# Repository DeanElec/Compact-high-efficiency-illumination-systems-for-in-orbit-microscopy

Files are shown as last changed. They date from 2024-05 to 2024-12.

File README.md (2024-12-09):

# Compact-high-efficiency-illumination-systems-for-in-orbit-microscopy
Presents all data associated with the development of my thesis for a 3rd year final year project at the University of Nottingham
***
## Project Overview
The aim of the project was to develop a solution to image specimens such as C. elegans and similar sized organisms in bright field and darkfield modalities, that would fit in a 1U Cube Sat (10cm^3) for less than £200.

***
## Project Evaluation
The project overall was a success as the system was able to take both bright field and dark field images with high enough resolution and resolving power to accurate image Diatoms, C.elegans and Buccal Epithelial Cells, however the code was not developed to run autonomously but the code developed for the Raspberry Pi as part of the GUI control could be quickly and easily modified to make a autonomous system due directly relevent code wrote in a generic way such that it can be reused.

Due to cost restraint a set of cheap lenses were used, but the datasheet that came with these lenses had all incorrect parameters such as FOV or MOD. For this reason significant time was spent characterising the lenses so the data could be relied upon.

For full evaluation of the design and the data my thesis can be found in the thesis directory.

### Images Taken on the Microscope
***
#### Diatoms Bright and Dark Field
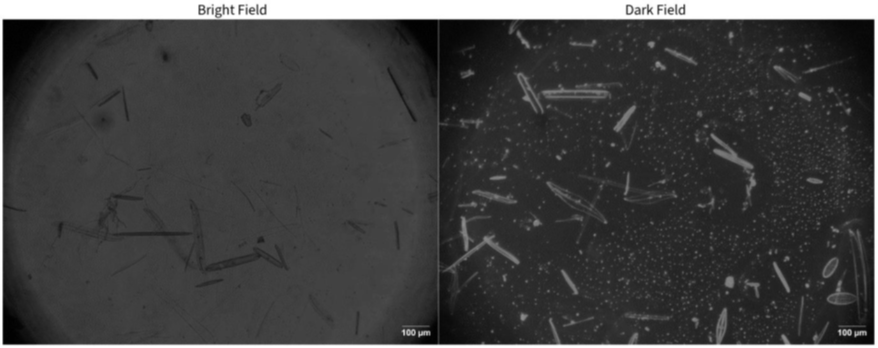
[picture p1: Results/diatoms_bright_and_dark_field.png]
Diatoms Bright and Dark Field


#### Buccal Epithelial Cells Bright and Dark Field
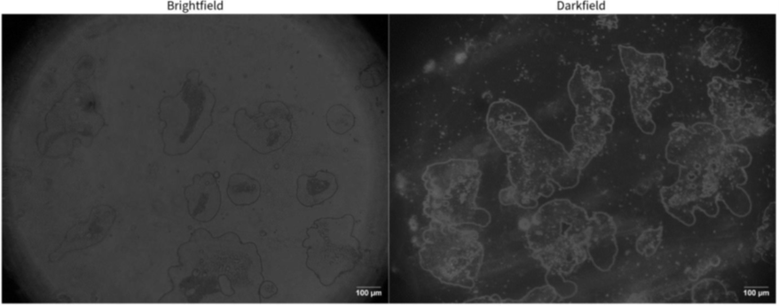
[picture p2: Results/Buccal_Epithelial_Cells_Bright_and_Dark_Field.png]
Buccal Epithelial Bright and Dark Field

***

### CAD Images of the Microscope System
***
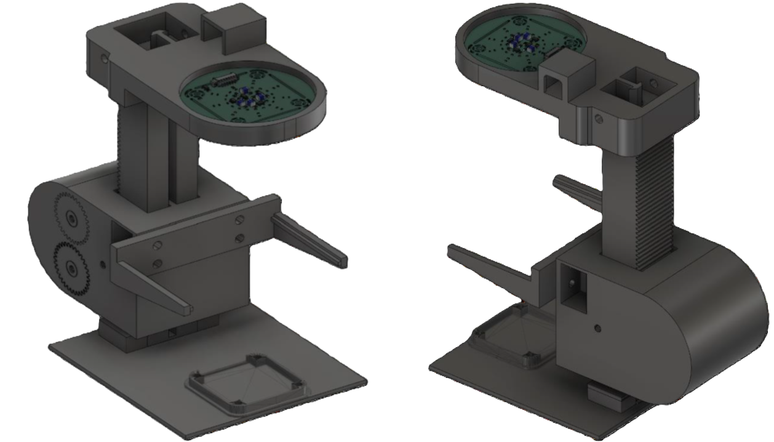
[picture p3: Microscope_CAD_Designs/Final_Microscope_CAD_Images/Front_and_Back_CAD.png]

***

## Control Interface
For ease of testing / taking images with the microscope a GUI was developed in C++ using QT to control all aspects of the microscope remotely when connected on the same network. This allowed for control of:
- Automatic transfer of the images taken on the Raspberry Pi to the host PC
- Save directory locations for both the Raspberry Pi side and the host PC side for saving the recieved images from the Raspberry Pi
- Brightness and PWM frequency controll of all 3 colour rings plus the central cyan LED used for rhinefield illumination
- Multiple basic (binary) image processing options such as the type of demosaic algorithm, and others
- Advanced image processing options such as custom brightness, white balance and gamma options
- Finally a button to allow the user to take an image once parameters have been set by the user
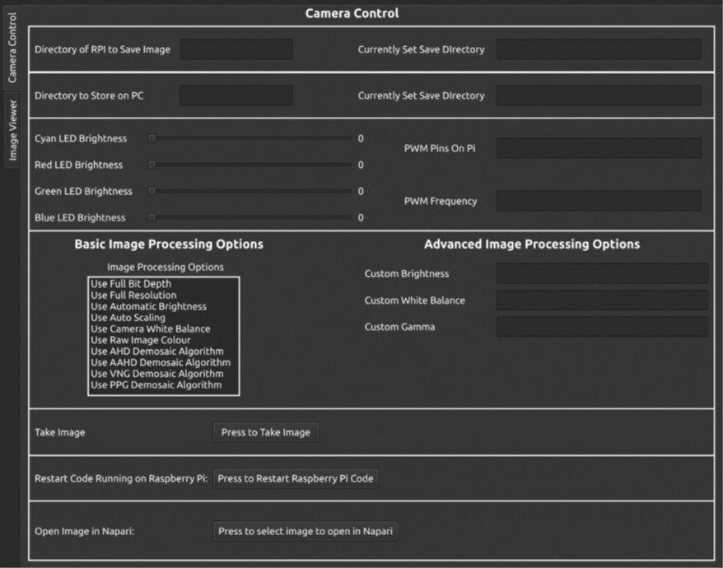
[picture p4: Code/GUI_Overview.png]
GUI Overview


## Future Work / Improvements
If this project was to be taken forward, the current PCB's would work but really require a PCB assembly house to manufacture and populate the board as it is too densely packed with too small component to do by hand and was a main struggle in the project.

That said an improved design for the illumination board has already been created and tested based on addressable SK6805 LEDs and will be uploaded to this github repo in the future once the driver board for it has been finalised and tested.
The new design will be able to be controlled via a plug-in for the open source microscopy software micro-manager, it will provide a GUI that will allow the user to control the illumination system from the host PC running micro-manager, as micro-manager
was wrote in java it is inherently cross platform and thus the plug-in should work for any OS.

Also as potential future upgrades would be to add a form of auto focus as although the microscope worked and gathered detailed images it was hard to get the specimens in focus.
***

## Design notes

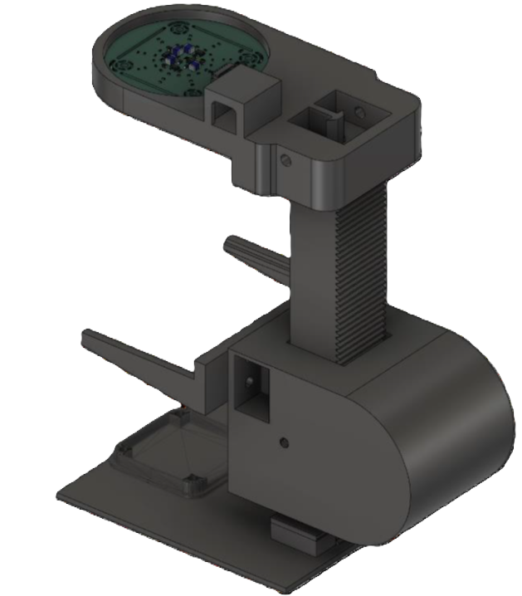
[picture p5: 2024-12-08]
Microscope_CAD_Designs/Final_Microscope_CAD_Images/Final_microscope_design_back.png

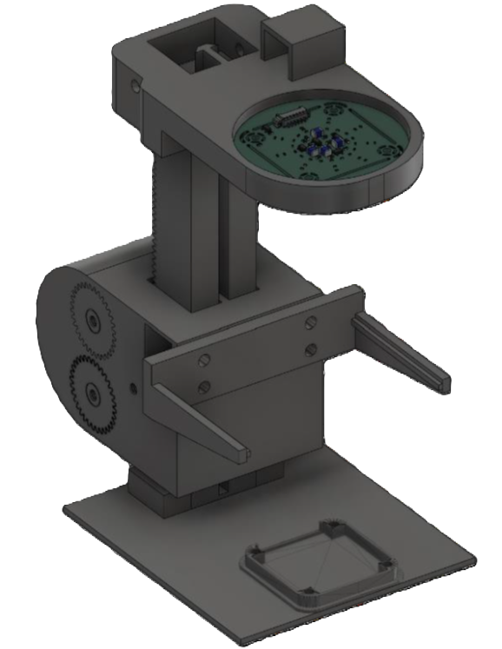
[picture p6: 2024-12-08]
Microscope_CAD_Designs/Final_Microscope_CAD_Images/Final_microscope_front.png

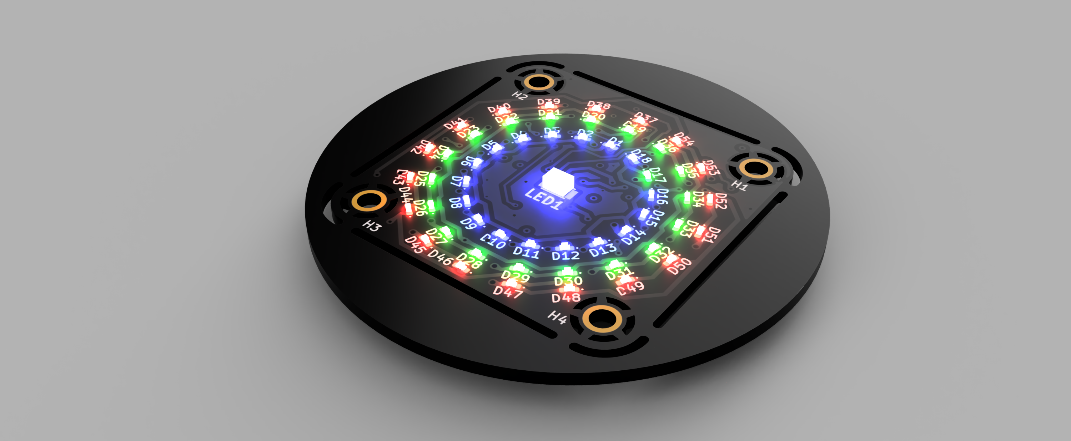
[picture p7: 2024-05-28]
PCB_Design/PCB_3_LED_Rings_Multiple_Thor_Labs_Mounting_Compatibility/LED_Revised_New_Rendered.png

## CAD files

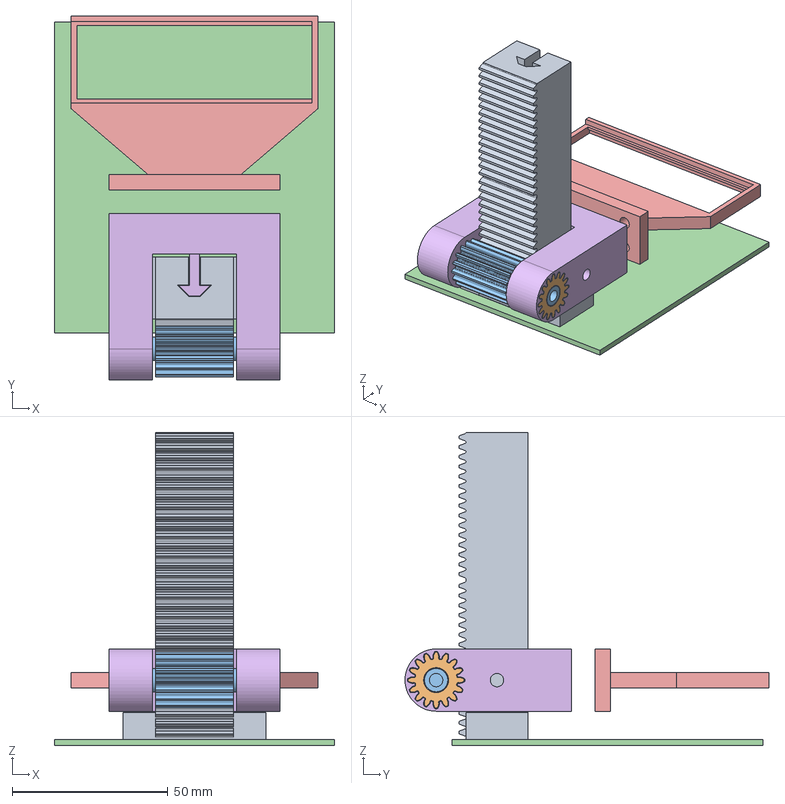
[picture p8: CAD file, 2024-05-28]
Microscope_CAD_Designs/Microscope_Stand_V1/Microscope_CAD_Design_V1_Files/Step_Files/Stand v1 assembled.step
90.0 x 116.9 x 100.5 mm
Rack Gear (16 teeth)
Spur Gear (16 teeth)
Spur to Rack Connector (2)
Spur to Rack Connector Left
Specimen Holder Universal Connector
Camera Holder
Base Plate Dimensions
Specimen_slide_holder

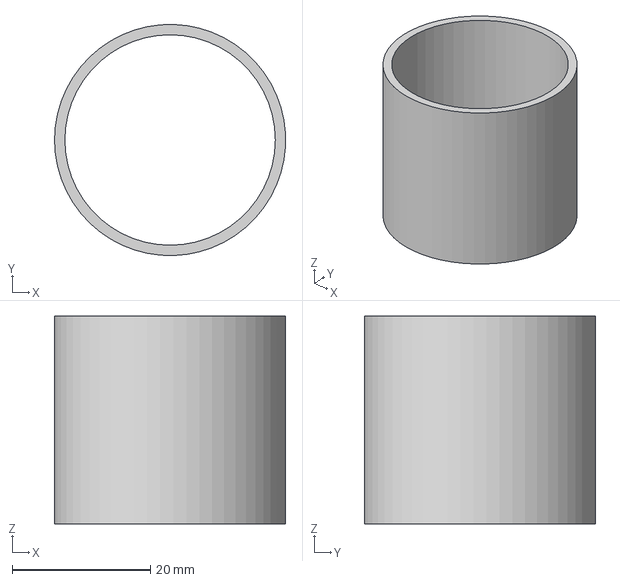
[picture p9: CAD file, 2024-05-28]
Microscope_CAD_Designs/Lens_Couplers_and_Adapters/Step_Files/m07-m03 lens coupler v2.step
33.4 x 33.4 x 30.0 mm

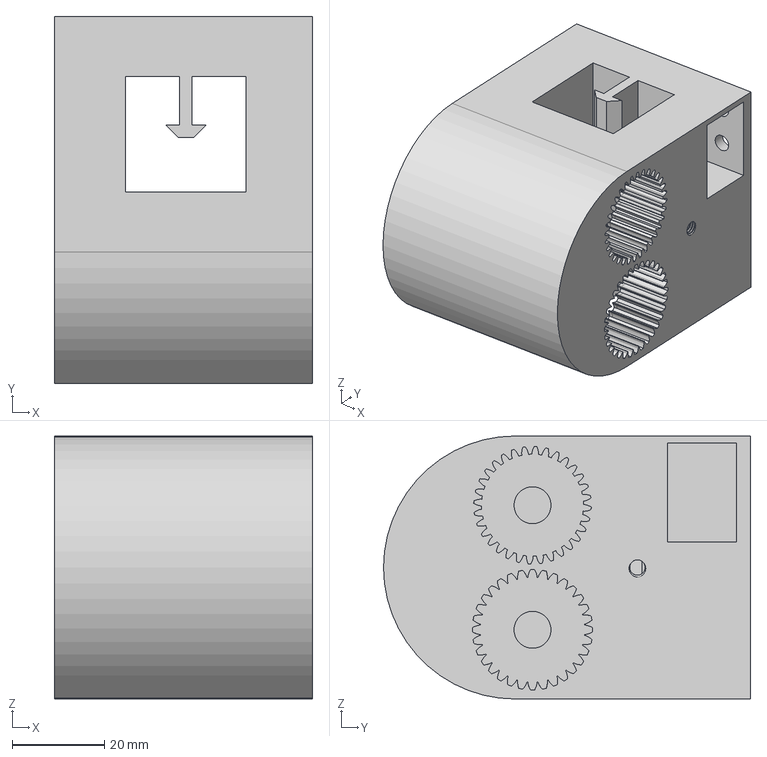
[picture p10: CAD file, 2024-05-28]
Microscope_CAD_Designs/Microscope_CAD_Design_V2_Files/Step_Files/New Spur to Rack Connector v22.step
56.0 x 79.6 x 57.0 mm

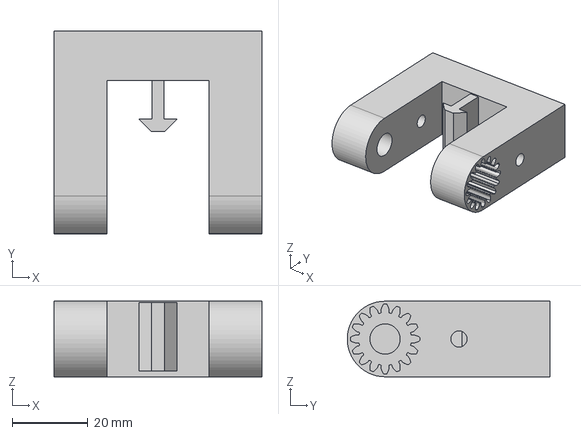
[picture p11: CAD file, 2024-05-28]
Microscope_CAD_Designs/Microscope_Stand_V1/Microscope_CAD_Design_V1_Files/Step_Files/Spur to rack connector v3.step
55.0 x 53.6 x 20.0 mm

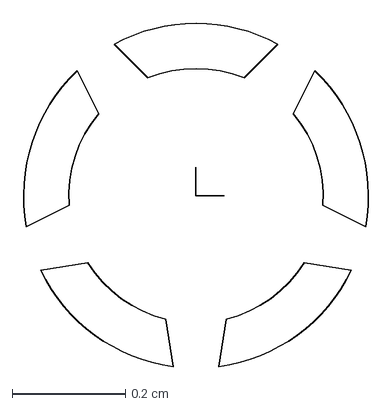
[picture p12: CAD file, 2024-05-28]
PCB_Design/PCB_3_LED_Rings_Multiple_Thor_Labs_Mounting_Compatibility/Hole Edge Cuts 2.5mm v6.dxf
0.637 x 0.62 cm

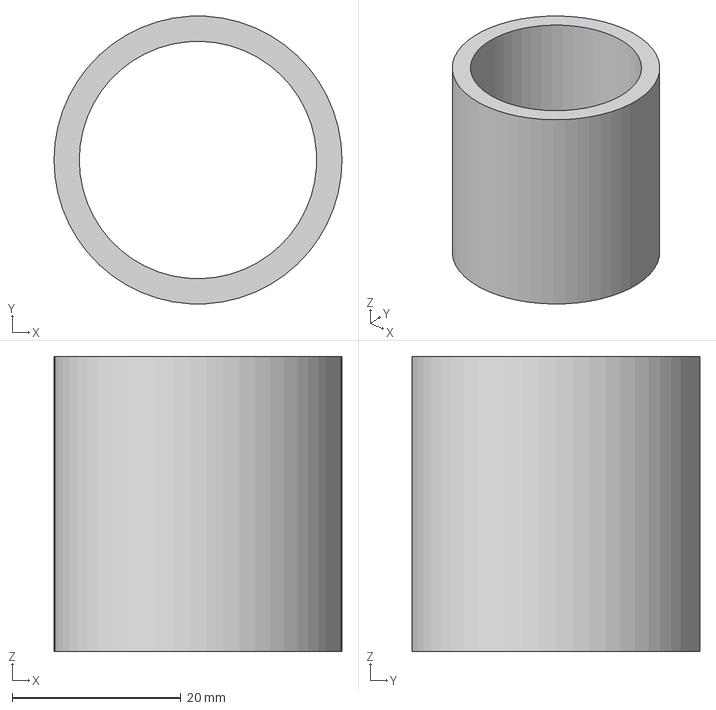
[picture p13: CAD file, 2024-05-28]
Microscope_CAD_Designs/Lens_Couplers_and_Adapters/Step_Files/Lens_to_Lens_Connector v3.step
34.1 x 34.1 x 35.0 mm

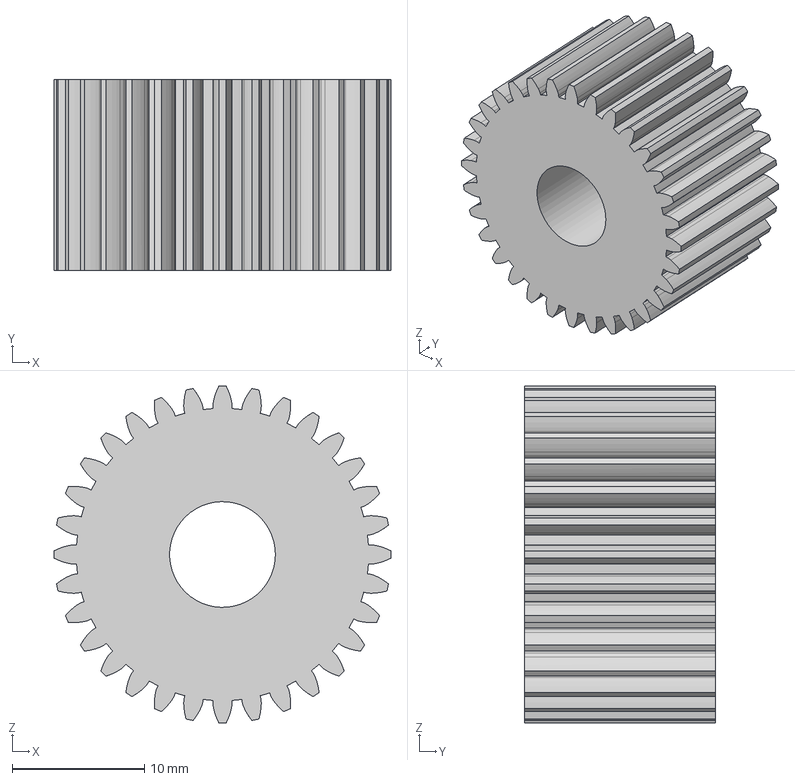
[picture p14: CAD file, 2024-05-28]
Microscope_CAD_Designs/Microscope_CAD_Design_V2_Files/Step_Files/New Spur Gear Shim.step
25.5 x 14.4 x 25.5 mm

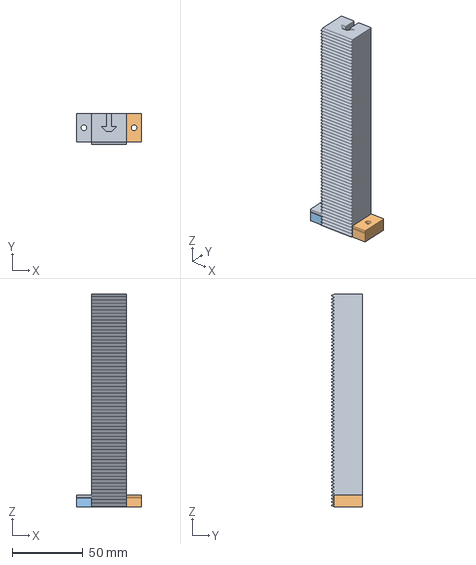
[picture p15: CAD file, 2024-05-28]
Microscope_CAD_Designs/Microscope_CAD_Design_V2_Files/Step_Files/Rack_Gear_New_Version v6.step
46.0 x 21.7 x 150.8 mm

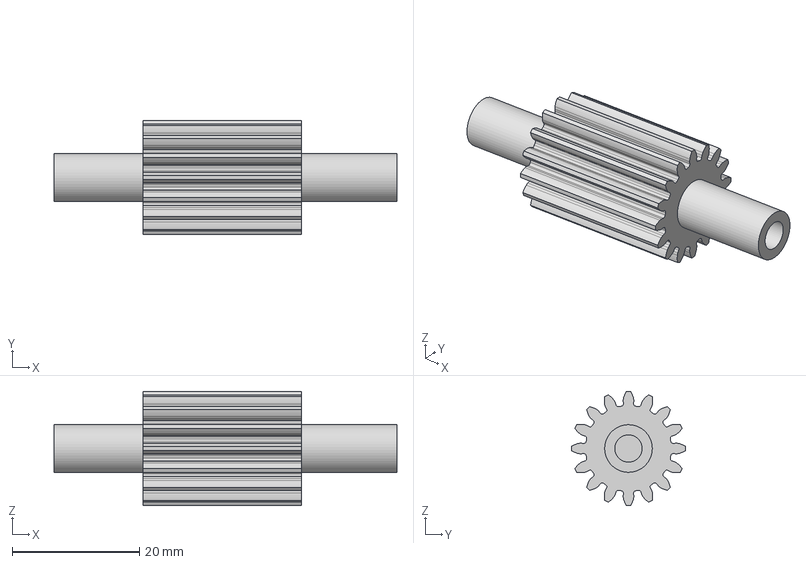
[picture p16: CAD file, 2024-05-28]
Microscope_CAD_Designs/Microscope_Stand_V1/Microscope_CAD_Design_V1_Files/Step_Files/Spur and Rod v3.step
54.0 x 18.0 x 18.0 mm

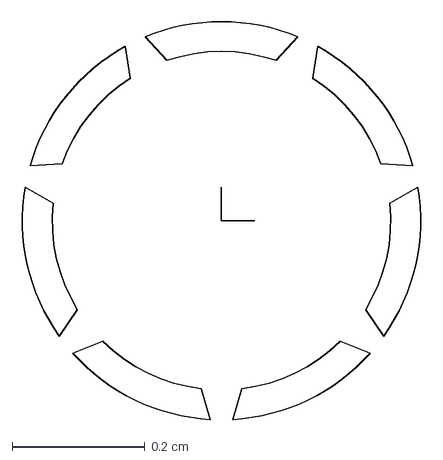
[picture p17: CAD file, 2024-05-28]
PCB_Design/PCB_3_LED_Rings_Multiple_Thor_Labs_Mounting_Compatibility/Hole Edge Cuts v5.dxf
0.618 x 0.607 cm

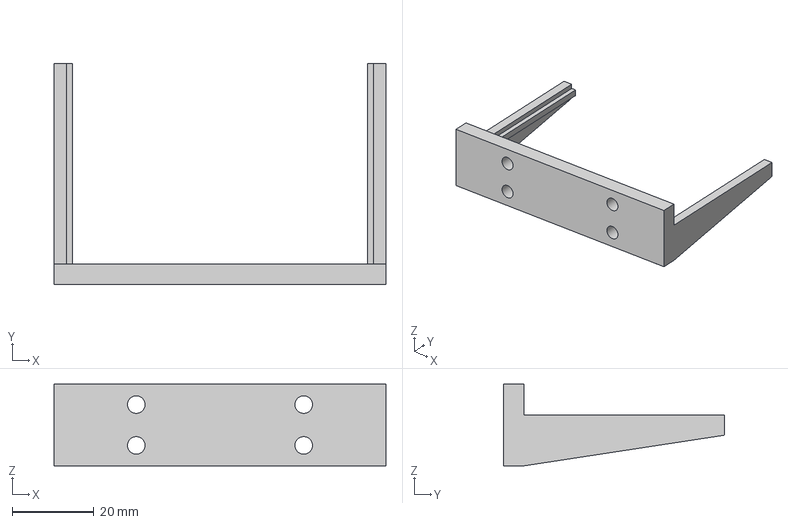
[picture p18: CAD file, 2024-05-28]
Microscope_CAD_Designs/Microscope_CAD_Design_V2_Files/Step_Files/New_Specimen_Holder_Wont_Obstruct_LED_Ring v5.step
81.3 x 54.1 x 20.0 mm

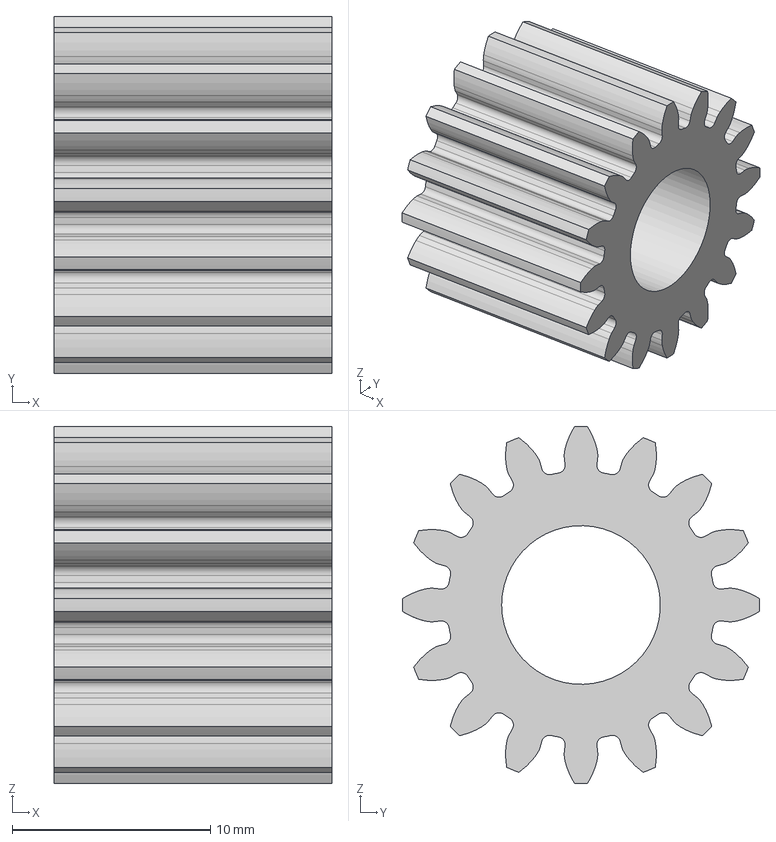
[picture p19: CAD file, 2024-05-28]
Microscope_CAD_Designs/Microscope_Stand_V1/Microscope_CAD_Design_V1_Files/Step_Files/Spur gear shaped shim v2.step
14.0 x 18.0 x 18.0 mm

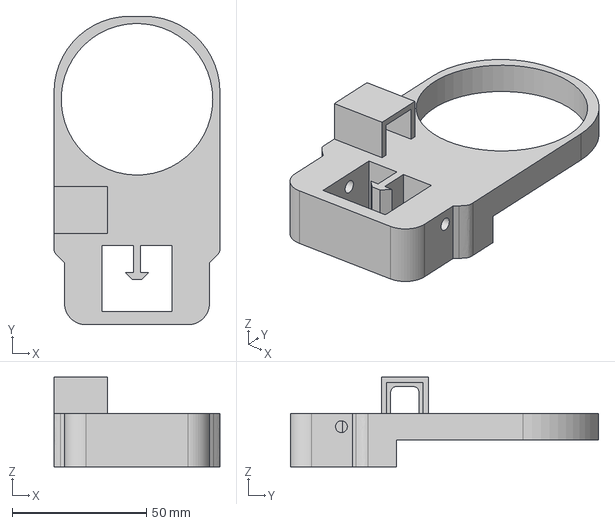
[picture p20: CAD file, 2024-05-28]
Microscope_CAD_Designs/Microscope_CAD_Design_V2_Files/Step_Files/Illumination_PCB_Holder v4.step
61.9 x 115.0 x 33.5 mm

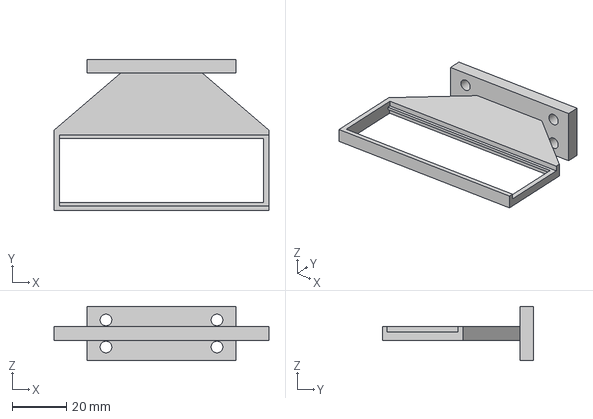
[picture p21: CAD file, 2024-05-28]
Microscope_CAD_Designs/Microscope_Stand_V1/Microscope_CAD_Design_V1_Files/Step_Files/Specimen_slide_holder v2.step
79.4 x 55.9 x 20.0 mm

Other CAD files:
Microscope_CAD_Designs/Lens_Couplers_and_Adapters/Step_Files/Lens_Adapter_m02_m07 v4.step
Microscope_CAD_Designs/Microscope_CAD_Design_V2_Files/Step_Files/New_Spur_and_Rod v4.step
Microscope_CAD_Designs/Microscope_Stand_V1/Microscope_CAD_Design_V1_Files/Step_Files/Camera_Holder v3.step
Microscope_CAD_Designs/Microscope_Stand_V1/Microscope_CAD_Design_V1_Files/Step_Files/Base Plate Dimensions v2.step
Microscope_CAD_Designs/Lens_Couplers_and_Adapters/Fusion_360_Files/Lens_Adapter_m02_m07 v4.f3d
Microscope_CAD_Designs/Lens_Couplers_and_Adapters/Fusion_360_Files/Lens_to_Lens_Connector v3.f3d
Microscope_CAD_Designs/Lens_Couplers_and_Adapters/Fusion_360_Files/m07-m03 lens coupler v2.f3d
Microscope_CAD_Designs/Microscope_CAD_Design_V2_Files/Fusion_360_Files/Illumination_PCB_Holder v3.f3d
Microscope_CAD_Designs/Microscope_CAD_Design_V2_Files/Fusion_360_Files/New_Specimen_Holder v5.f3d
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

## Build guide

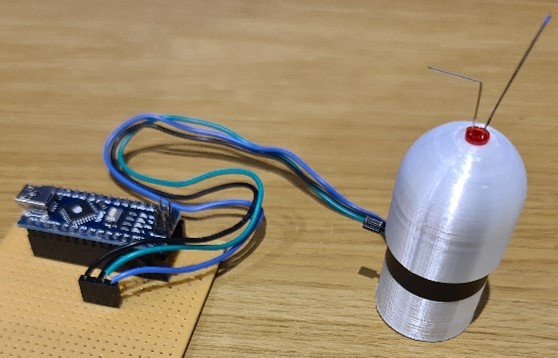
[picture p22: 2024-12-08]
Lens-characterisation/light_transmission_efficiency/light_intensity_setup_with_a_lens.jpg

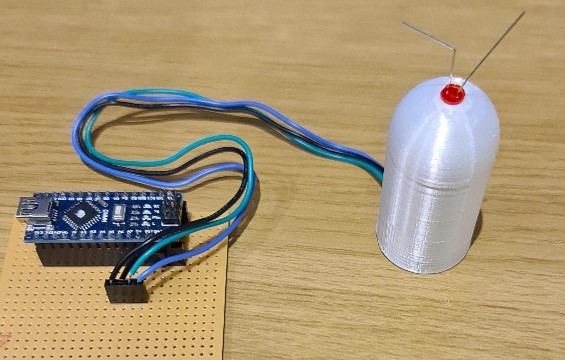
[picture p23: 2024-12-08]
Lens-characterisation/light_transmission_efficiency/no_lens_light_intensity_setup_for_baseline.jpg

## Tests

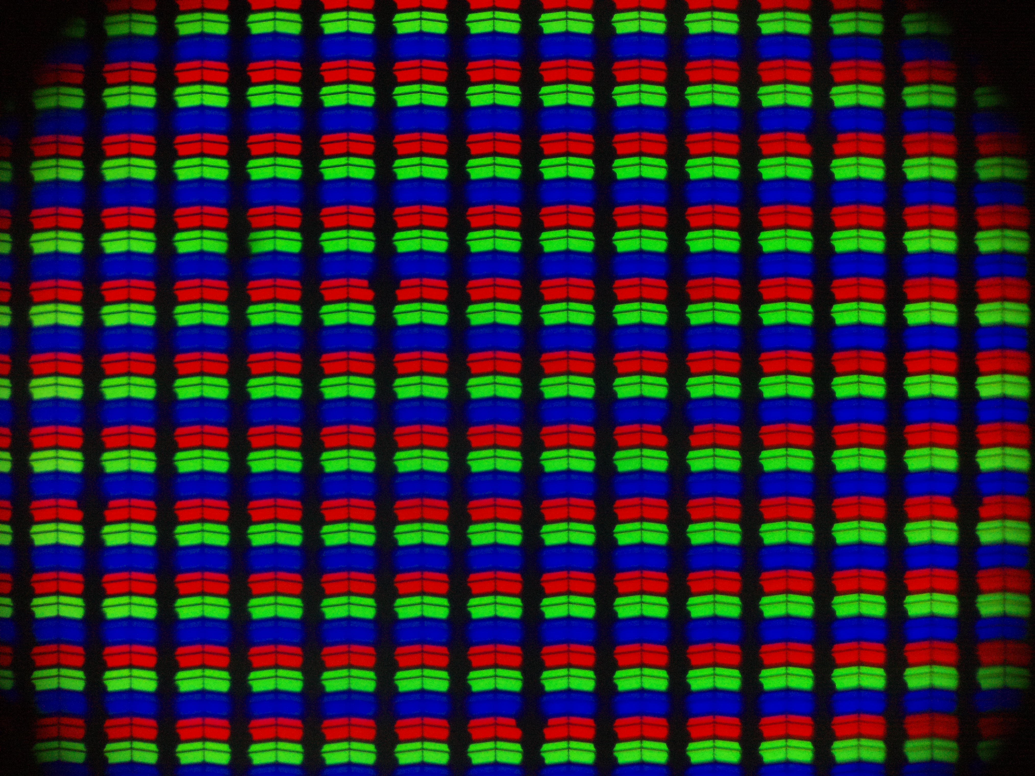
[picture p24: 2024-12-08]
Lens-characterisation/resolving_power_and_chromatic_aberration/rgb_pixels_M02_M01_new.jpeg

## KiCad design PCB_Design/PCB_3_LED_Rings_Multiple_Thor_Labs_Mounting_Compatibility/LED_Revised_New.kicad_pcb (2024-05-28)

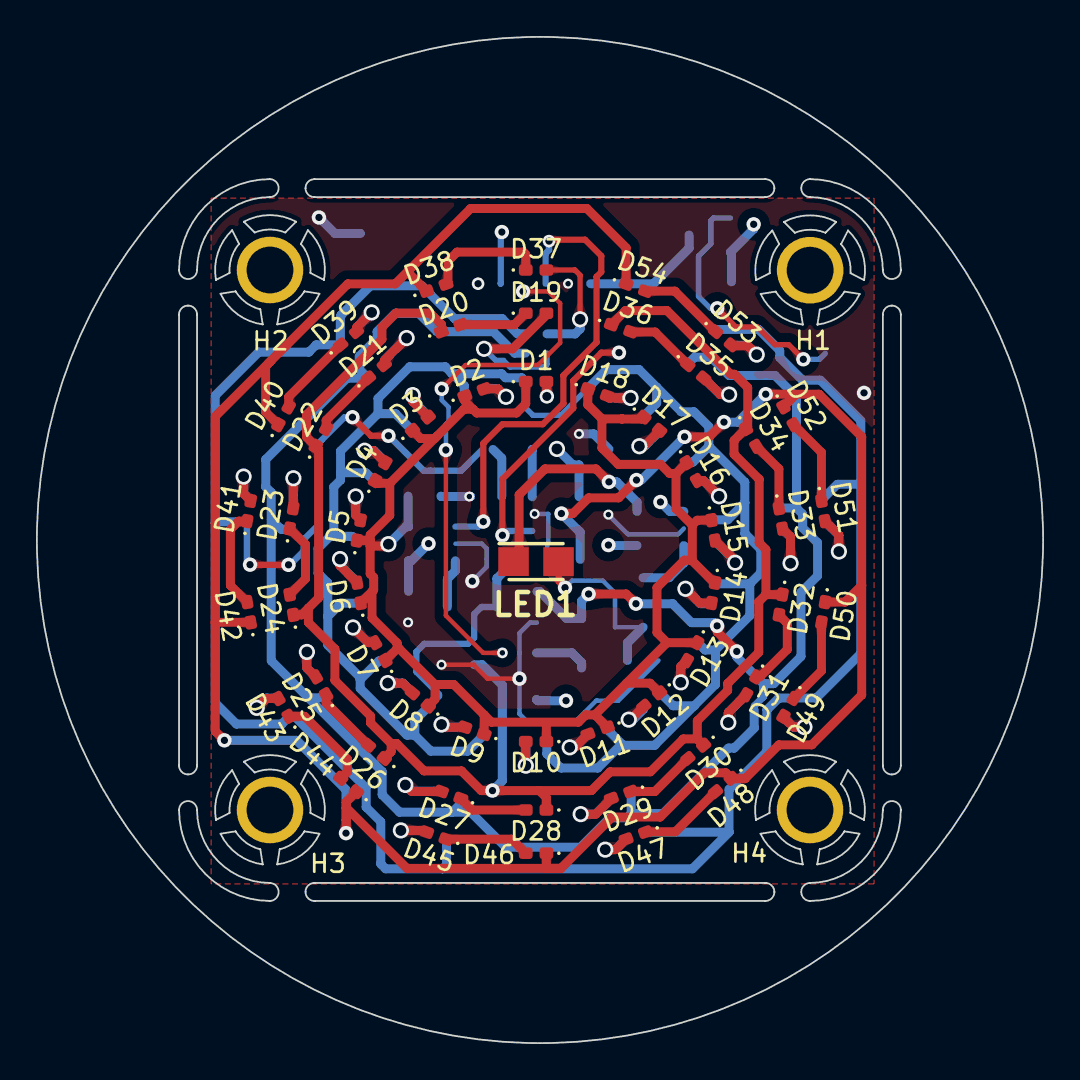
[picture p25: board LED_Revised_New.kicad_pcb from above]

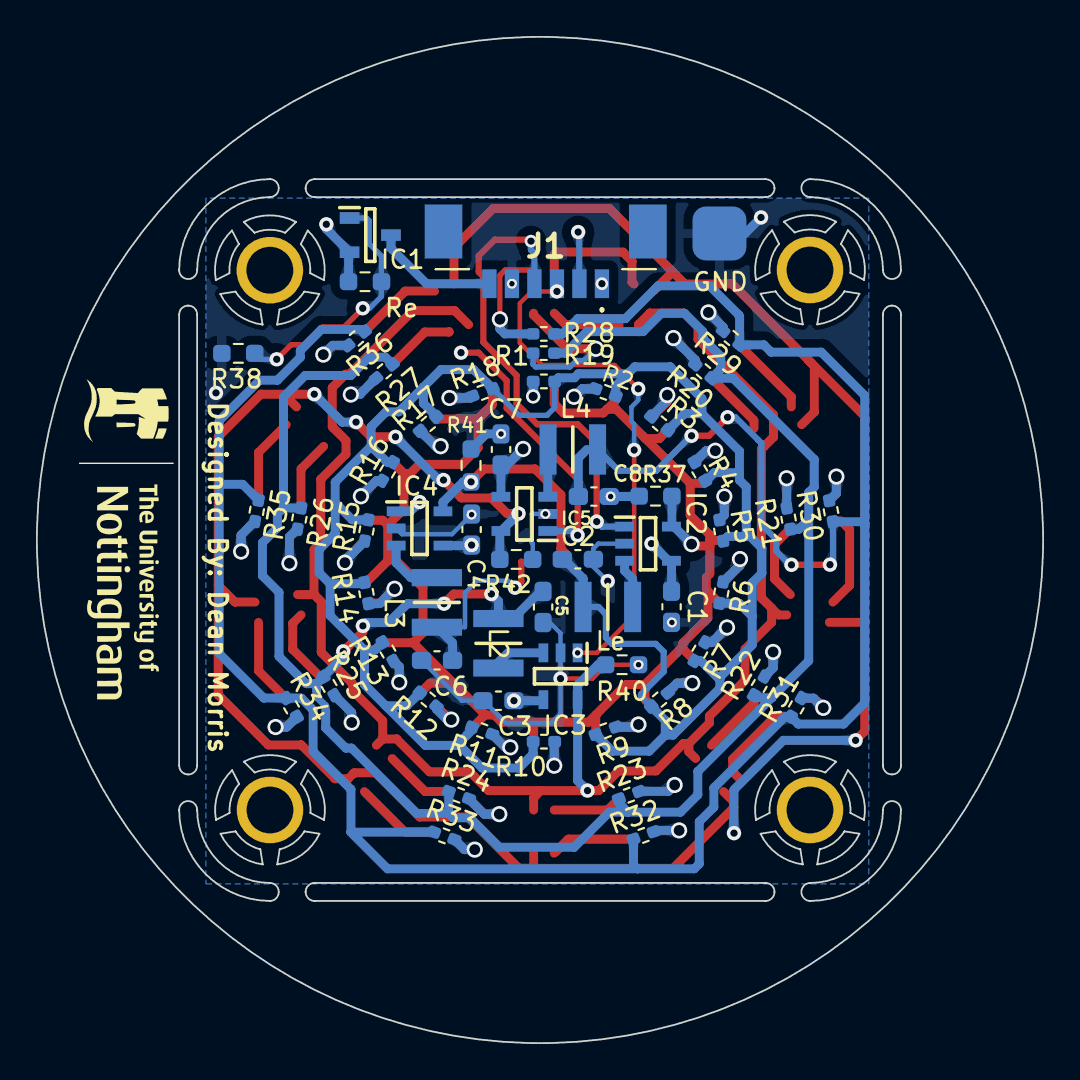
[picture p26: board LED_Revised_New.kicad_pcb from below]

Board: 4 copper layers, 55.9 x 55.9 mm, 120 parts (61 on the bottom side), 74 nets.

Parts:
C1, C2, C3, C4, C5, C6, C7, C8: 10uF; C_0603_1608Metric_Pad1.08x0.95mm_HandSolder
D1, D2, D3, D4, D5, D6, D7, D8, D9, D10, D11, D12, D13, D14, D15, D16, D17, D18, D19, D20, D21, D22, D23, D24, D25, D26, D27, D28, D29, D30, D31, D32, D33, D34, D35, D36, D37, D38, D39, D40, D41, D42, D43, D44, D45, D46, D47, D48, D49, D50, D51, D52, D53, D54: LED_0402_1005Metric_Pad0.77x0.64mm_HandSolder
H1, H2, H3, H4: MountingHole_Pad; M2.5_Mountinh_Hole
H6: SMD_Ground_Pad; 3mm_Ground_Pad
IC1: FDN360P; SOT95P251X112-3N
IC2, IC3, IC4, IC5: PAM2804AAB010; SOT95P280X100-5N
J1: Conn_01x06_Socket; 532610671
L2, L3, L4: 4.7uH; DFE322520FD1R0MP2
LED1: AA3021VRCBS_A; LEDM3020X150N
Le: 4.7uH; DFE322520FD1R0MP2
R1, R2, R3, R4, R5, R6, R7, R8, R9, R10, R11, R12, R13, R14, R15, R16, R17, R18, R19, R20, R21, R22, R23, R24, R25, R26, R27, R28, R29, R30, R31, R32, R33, R34, R35, R36: 100; R_0402_1005Metric_Pad0.72x0.64mm_HandSolder
R37, R40, R42: R; R_0603_1608Metric_Pad0.98x0.95mm_HandSolder
R38: 10k; R_0603_1608Metric_Pad0.98x0.95mm_HandSolder
R41: 3.6; R_0603_1608Metric_Pad0.98x0.95mm_HandSolder
Re: 10k; R_0603_1608Metric_Pad0.98x0.95mm_HandSolder

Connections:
/SW: IC4.3 (SW), L3.2
Blue_LED_End: D1.1 (K), D2.1 (K), D3.1 (K), D4.1 (K), D5.1 (K), D6.1 (K), D7.1 (K), D8.1 (K), D9.1 (K), D10.1 (K), D11.1 (K), D12.1 (K), D13.1 (K), D14.1 (K), D15.1 (K), D16.1 (K), D17.1 (K), D18.1 (K), IC2.5 (FB), R37.1
Blue_LED_Start: C2.1, Le.1, R1.1, R2.1, R3.1, R4.1, R5.1, R6.1, R7.1, R8.1, R9.1, R10.1, R11.1, R12.1, R13.1, R14.1, R15.1, R16.1, R17.1, R18.1
GND: C1.2, C2.2, C3.2, C4.2, C5.2, C6.2, C7.2, C8.2, H6.1, IC2.2 (GND), IC3.2 (GND), IC4.2 (GND), IC5.2 (GND), J1.5, R37.2, R38.1, R40.2, R41.2, R42.2
Green_LED_End: D20.1 (K), D22.1 (K), D24.1 (K), D26.1 (K), D28.1 (K), D30.1 (K), D32.1 (K), D34.1 (K), D36.1 (K), IC3.5 (FB), R40.1
Green_LED_Start: C5.1, L2.1, R19.1, R20.1, R21.1, R22.1, R23.1, R24.1, R25.1, R26.1, R27.1
unnamed: D1.2 (A), R1.2
unnamed: D2.2 (A), R2.2
unnamed: D3.2 (A), R3.2
unnamed: D4.2 (A), R4.2
unnamed: D5.2 (A), R5.2
unnamed: D6.2 (A), R6.2
unnamed: D7.2 (A), R7.2
unnamed: D8.2 (A), R8.2
unnamed: D9.2 (A), R9.2
unnamed: D10.2 (A), R10.2
unnamed: D11.2 (A), R11.2
unnamed: D12.2 (A), R12.2
unnamed: D13.2 (A), R13.2
unnamed: D14.2 (A), R14.2
unnamed: D15.2 (A), R15.2
unnamed: D16.2 (A), R16.2
unnamed: D17.2 (A), R17.2
unnamed: D18.2 (A), R18.2
unnamed: D19.2 (A), R19.2
unnamed: D19.1 (K), D20.2 (A)
unnamed: D21.2 (A), R20.2
unnamed: D21.1 (K), D22.2 (A)
unnamed: D23.2 (A), R21.2
unnamed: D23.1 (K), D24.2 (A)
unnamed: D25.2 (A), R22.2
unnamed: D25.1 (K), D26.2 (A)
unnamed: D27.2 (A), R23.2
unnamed: D27.1 (K), D28.2 (A)
unnamed: D29.2 (A), R24.2
unnamed: D29.1 (K), D30.2 (A)
unnamed: D31.2 (A), R25.2
unnamed: D31.1 (K), D32.2 (A)
unnamed: D33.2 (A), R26.2
unnamed: D33.1 (K), D34.2 (A)
unnamed: D35.2 (A), R27.2
unnamed: D35.1 (K), D36.2 (A)
unnamed: D37.2 (A), R28.2
unnamed: D37.1 (K), D38.2 (A)
unnamed: D39.2 (A), R29.2
unnamed: D39.1 (K), D40.2 (A)
unnamed: D41.2 (A), R30.2
unnamed: D41.1 (K), D42.2 (A)
unnamed: D43.2 (A), R31.2
unnamed: D43.1 (K), D44.2 (A)
unnamed: D45.2 (A), R32.2
unnamed: D45.1 (K), D46.2 (A)
unnamed: D47.2 (A), R33.2
unnamed: D47.1 (K), D48.2 (A)
unnamed: D49.2 (A), R34.2
unnamed: D49.1 (K), D50.2 (A)
unnamed: D51.2 (A), R35.2
unnamed: D51.1 (K), D52.2 (A)
unnamed: D53.2 (A), R36.2
unnamed: D53.1 (K), D54.2 (A)
unnamed: IC1.1 (G), R38.2, Re.1
unnamed: IC2.3 (SW), Le.2
unnamed: IC3.3 (SW), L2.2
unnamed: IC4.5 (FB), LED1.1 (K), R41.1
unnamed: IC5.3 (SW), L4.2
unnamed: C6.1, L3.1, LED1.2 (A)
PWM_Cyan_LED: IC4.1 (EN), J1.1
PWM_Inner_LED_RIng: IC2.1 (EN), J1.4
PWM_Middle_LED_RIng: IC3.1 (EN), J1.3
PWM_Outer_LED_Ring: IC5.1 (EN), J1.2
Red_LED_End: D38.1 (K), D40.1 (K), D42.1 (K), D44.1 (K), D46.1 (K), D48.1 (K), D50.1 (K), D52.1 (K), D54.1 (K), IC5.5 (FB), R42.1
Red_LED_Start: C8.1, L4.1, R28.1, R29.1, R30.1, R31.1, R32.1, R33.1, R34.1, R35.1, R36.1
Vin: IC1.3 (D), J1.6
Vin_Protected: C1.1, C3.1, C4.1, C7.1, IC1.2 (S), IC2.4 (VIN), IC3.4 (VIN), IC4.4 (VIN), IC5.4 (VIN), Re.2

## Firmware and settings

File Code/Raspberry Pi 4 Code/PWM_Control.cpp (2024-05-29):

#include "PWM_Control.h"

using namespace std;
//------------------------Constructor definitions---------------------------
PWM_Control::PWM_Control(int Red_PWM_Pin_,
                         int Green_PWM_Pin_,
                         int Blue_PWM_Pin_,
                         int Cyan_PWM_Pin_,
                         int Red_Brightness_,
                         int Green_Brightness_,
                         int Blue_Brightness_,
                         int Cyan_Brightness_,
                         int PWM_Frequency_)
    : Red_PWM_Pin(Red_PWM_Pin_),
      Green_PWM_Pin(Green_PWM_Pin_),
      Blue_PWM_Pin(Blue_PWM_Pin_),
      Cyan_PWM_Pin(Cyan_PWM_Pin_),
      Red_Brightness(Red_Brightness_),
      Green_Brightness(Green_Brightness_),
      Blue_Brightness(Blue_Brightness_),
      Cyan_Brightness(Cyan_Brightness_),
      PWM_Frequency(PWM_Frequency_) {}
//-------------------------------------------------------------------------

//------------------------------copy constructor----------------------
PWM_Control::PWM_Control(const PWM_Control& PWM)
    : Red_PWM_Pin(PWM.Red_PWM_Pin),
      Green_PWM_Pin(PWM.Green_PWM_Pin),
      Blue_PWM_Pin(PWM.Blue_PWM_Pin),
      Cyan_PWM_Pin(PWM.Cyan_PWM_Pin),
      Red_Brightness(PWM.Red_Brightness),
      Green_Brightness(PWM.Green_Brightness),
      Blue_Brightness(PWM.Blue_Brightness),
      Cyan_Brightness(PWM.Cyan_Brightness),
      PWM_Frequency(PWM.PWM_Frequency) {}
//----------------------------------------------------------------------


//-----------------------equals function-------------------------------------
PWM_Control& PWM_Control::operator=(const PWM_Control& PWM) {
    if (this == &PWM)
        return (*this);

    Red_PWM_Pin = PWM.Red_PWM_Pin;
    Green_PWM_Pin = PWM.Green_PWM_Pin;
    Blue_PWM_Pin = PWM.Blue_PWM_Pin;
    Cyan_PWM_Pin = PWM.Cyan_PWM_Pin;

    Red_Brightness = PWM.Red_Brightness;
    Green_Brightness = PWM.Green_Brightness;
    Blue_Brightness = PWM.Blue_Brightness;
    Cyan_Brightness = PWM.Cyan_Brightness;

    PWM_Frequency = PWM.PWM_Frequency;

    return (*this);
}
//---------------------------------------------------------------------------


//------------------------get function definitions-------------------
int PWM_Control::get_Red_Brightness() { return Red_Brightness; }
int PWM_Control::get_Green_Brightness() { return Green_Brightness; }
int PWM_Control::get_Blue_Brightness() { return Blue_Brightness; }
int PWM_Control::get_Cyan_Brightness() { return Cyan_Brightness; }

int PWM_Control::get_Red_PWM_Pin() { return Red_PWM_Pin; }
int PWM_Control::get_Green_PWM_Pin() { return Green_PWM_Pin; }
int PWM_Control::get_Blue_PWM_Pin() { return Blue_PWM_Pin; }
int PWM_Control::get_Cyan_PWM_Pin() { return Cyan_PWM_Pin; }

int PWM_Control::get_PWM_Frequency() { return PWM_Frequency; }


//--------------------------------------------------------------------

void PWM_Control::set_All_Brightnesses(int _Red_Brightness, int _Green_Brightness, int _Blue_Brightness, int _Cyan_Brightness){
    if (_Red_Brightness >= 0 && _Red_Brightness <= 100) { //100 different values for duty cycle control
        Red_Brightness = _Red_Brightness;
        gpioPWM(get_Red_PWM_Pin(), Red_Brightness);
    } else {
        cerr << "Error: Invalid Brightness value, value range is 0-1000" << endl;
    }
    
    if (_Green_Brightness >= 0 && _Green_Brightness <= 100) { //100 different values for duty cycle control
        Green_Brightness = _Green_Brightness;
        gpioPWM(get_Green_PWM_Pin(), Green_Brightness);
    } else {
        cerr << "Error: Invalid Brightness value, value range is 0-1000" << endl;
    } 
    
    if (_Blue_Brightness >= 0 && _Blue_Brightness <= 100) { //100 different values for duty cycle control
        Blue_Brightness = _Blue_Brightness;
        gpioPWM(get_Blue_PWM_Pin(), Blue_Brightness);
    } else {
        cerr << "Error: Invalid Brightness value, value range is 0-1000" << endl;
    }
    
    if (_Cyan_Brightness >= 0 && _Cyan_Brightness <= 100) { //100 different values for duty cycle control
        Cyan_Brightness = _Cyan_Brightness;
        gpioPWM(get_Cyan_PWM_Pin(), Cyan_Brightness);
    } else {
        cerr << "Error: Invalid Brightness value, value range is 0-1000" << endl;
    }
}


void PWM_Control::set_Red_Brightness(int _Red_Brightness) {
    if (_Red_Brightness >= 0 && _Red_Brightness <= 100) { //100 different values for duty cycle control
        Red_Brightness = _Red_Brightness;
        gpioPWM(get_Red_PWM_Pin(), Red_Brightness);
    } else {
        cerr << "Error: Invalid Brightness value, value range is 0-1000" << endl;
    }
}


void PWM_Control::set_Green_Brightness(int _Green_Brightness) {
    if (_Green_Brightness >= 0 && _Green_Brightness <= 100) { //100 different values for duty cycle control
        Green_Brightness = _Green_Brightness;
        gpioPWM(get_Green_PWM_Pin(), Green_Brightness);
    } else {
        cerr << "Error: Invalid Brightness value, value range is 0-1000" << endl;
    }
}


void PWM_Control::set_Blue_Brightness(int _Blue_Brightness) {
    if (_Blue_Brightness >= 0 && _Blue_Brightness <= 100) { //100 different values for duty cycle control
        Blue_Brightness = _Blue_Brightness;
        gpioPWM(get_Blue_PWM_Pin(), Blue_Brightness);
    } else {
        cerr << "Error: Invalid Brightness value, value range is 0-1000" << endl;
    }
}


void PWM_Control::set_Cyan_Brightness(int _Cyan_Brightness) {
    if (_Cyan_Brightness >= 0 && _Cyan_Brightness <= 100) { //100 different values for duty cycle control
        Cyan_Brightness = _Cyan_Brightness;
        gpioPWM(get_Cyan_PWM_Pin(), Cyan_Brightness);
    } else {
        cerr << "Error: Invalid Brightness value, value range is 0-1000" << endl;
    }
}


void PWM_Control::set_Red_PWM_Pin(int _Red_PWM_Pin) {
    if (_Red_PWM_Pin >= 2 && _Red_PWM_Pin <= 27) { //starts at 2 as GPIO 0 and 1 are reserved
        Red_PWM_Pin = _Red_PWM_Pin;
    } else {
        cerr << "Error: Invalid GPIO Pin Number, the range is 0-27" << endl;
    }
}


void PWM_Control::set_Green_PWM_Pin(int _Green_PWM_Pin) {
    if (_Green_PWM_Pin >= 2 && _Green_PWM_Pin <= 27) { //starts at 2 as GPIO 0 and 1 are reserved
        Green_PWM_Pin = _Green_PWM_Pin;
    } else {
        cerr << "Error: Invalid GPIO Pin Number, the range is 0-27" << endl;
    }
}


void PWM_Control::set_Blue_PWM_Pin(int _Blue_PWM_Pin) {
    if (_Blue_PWM_Pin >= 2 && _Blue_PWM_Pin <= 27) { //starts at 2 as GPIO 0 and 1 are reserved
        Blue_PWM_Pin = _Blue_PWM_Pin;
    } else {
        cerr << "Error: Invalid GPIO Pin Number, the range is 0-27" << endl;
    }
}


void PWM_Control::set_Cyan_PWM_Pin(int _Cyan_PWM_Pin) {
    if (_Cyan_PWM_Pin >= 2 && _Cyan_PWM_Pin <= 27) { //starts at 2 as GPIO 0 and 1 are reserved
        Cyan_PWM_Pin = _Cyan_PWM_Pin;
    } else {
        cerr << "Error: Invalid GPIO Pin Number, the range is 0-27" << endl;
    }
}
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

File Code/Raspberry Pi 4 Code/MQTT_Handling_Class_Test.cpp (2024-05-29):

//----------For PIGPIO Code----------
#include <iostream>
#include <pigpio.h>
//-----------------------------------


//----------For MQTT Code----------		
#include <mosquitto.h>
#include <stdio.h>
#include <errno.h>
#include <chrono>
#include <string.h>
#include <cstdlib>
//---------------------------------


//-----Personally Made Libraries-----
#include "MQTT_Publisher.h"
#include "IPAddress.h"
#include "DateTime.h"
#include "File_Monitor.h"
#include "Socket_Comms.h"
#include "PWM_Control.h"
//------------------------------------


//-----includes for file monitoring-----
#include <stdlib.h>
#include <sys/types.h>
#include <sys/inotify.h>
#include <unistd.h>
#include <thread>
//--------------------------------------

//-----additional needed libraries-----
#include <string>
#include <Python.h>
#include <map>
#include <fcntl.h> // for fcntl
#include <errno.h> // for errno, EAGAIN, EWOULDBLOCK
//-------------------------------------

#include <sstream>
#include <vector>

#include <filesystem>


#include <csignal>
#include <atomic>

using namespace std;

namespace Updated_Advanced_Image_Processing_Options_Parameters{
	string Custom_Brightness_Value_Updated;
	string Custom_White_Balance_Values_Updated;
	string Custom_Gamma_Values_Updated;
}


namespace Directory_Parameters{
	string RPi_Save_Directory;
	string Confirmed_Correct_RPi_Save_Directory;
	string PC_Save_Directory;
}

namespace Linux_PC_SCP_Parameters{
	string Linux_PC_WhoAmI;
	string Linux_PC_IP;
}

namespace PWM_Parameters{
	int Cyan_LED_PWM_Pin;
	int Red_LED_PWM_Pin;
	int Green_LED_PWM_Pin;
	int Blue_LED_PWM_Pin;
	
	int PWM_Frequency;
	
	int Cyan_LED_Brightness;
	int Red_LED_Brightness;
	int Green_LED_Brightness;
	int Blue_LED_Brightness;
}


std::atomic<bool> keepRunning(true);//atomic flag needed to control the program loop as cant ctrl + c out without
								    //this and Handle_Signal()

//signal handler function
void Handle_Signal(int signal) {
    cout << "Caught signal " << signal << ", stopping..." << endl;;
    keepRunning = false;
}



string removeExtension(const string& filename) {
    //find the last occurrence of '.' as this is the start of the file extension
    size_t Last_Dot = filename.find_last_of(".");
    if (Last_Dot == string::npos) return filename; //if somehow no extension found
    //remove from the last dot to the end of the string
    return filename.substr(0, Last_Dot);
}





std::map<string, string> Post_Processing_Parameters_Map;

map<int, pair<string, string>> selectionToParameters = {
    {0, {"output_bps", "16"}},
    {1, {"half_size", "False"}},
    {2, {"no_auto_bright", "True"}},
    {3, {"no_auto_scale", "False"}},
    {4, {"use_camera_wb", "True"}},
    {5, {"output_color", "rawpy.ColorSpace.raw"}},
    {6, {"demosaic_algorithm", "rawpy.DemosaicAlgorithm.AHD"}},
    {7, {"demosaic_algorithm", "rawpy.DemosaicAlgorithm.AAHD"}},
    {8, {"demosaic_algorithm", "rawpy.DemosaicAlgorithm.VNG"}},
    {9, {"demosaic_algorithm", "rawpy.DemosaicAlgorithm.PPG"}},
    
    {10, {"bright", Updated_Advanced_Image_Processing_Options_Parameters::Custom_Brightness_Value_Updated}},
    {11, {"user_wb", Updated_Advanced_Image_Processing_Options_Parameters::Custom_White_Balance_Values_Updated}},
    {12, {"gamma", Updated_Advanced_Image_Processing_Options_Parameters::Custom_Gamma_Values_Updated}},
    // Add additional mappings as needed
};



void sendIPAddressAndAwaitConfirmation() {
    int sock = socket(AF_INET, SOCK_DGRAM, 0); //create a UDP socket for IPV4 comms
    if (sock < 0) {
        cerr << "Error creating socket." << endl;
        return;
    }

    sockaddr_in serverAddr;
    serverAddr.sin_family = AF_INET; //buffer size set for IPv4 addresses
    serverAddr.sin_port = htons(8080); //set the port
    inet_pton(AF_INET, "224.0.0.251", &serverAddr.sin_addr); //place holder address set here

    
    fcntl(sock, F_SETFL, O_NONBLOCK); //make the socket non-blocking

    FILE* ipFile = popen("hostname -I", "r"); //gets the pi IP address cant use system() as doesnt allow to store the output
    if (ipFile == NULL) {
        cerr << "Error opening file." << endl;
        close(sock);
        return;
    }
	
//------reads the ip address into ipAddress------
    char ipAddress[16];
    if (fscanf(ipFile, "%s", ipAddress) == 0) {
        cerr << "Failed to read IP address." << endl;
        pclose(ipFile);
        close(sock);
        return;
    }
    pclose(ipFile);
//---------------------------------------------


    cout << "Raspberry Pi's IP address: " << ipAddress << endl;

//-----variables needed for waiting for confirmation loop-----
    bool confirmed = false;
    char buffer[1024];
    sockaddr_in fromAddr;
    socklen_t fromAddrLen = sizeof(fromAddr);
//------------------------------------------------------------


    while (!confirmed) { //while confirmed is false continue to loop
        // Send the IP address to the Linux PC
        sendto(sock, ipAddress, strlen(ipAddress), 0, (struct sockaddr*)&serverAddr, sizeof(serverAddr));

        //wait for a half a second before checking for a response
        std::this_thread::sleep_for(std::chrono::milliseconds(500));

        //check for a confirmation message from the Linux PC
        ssize_t respLength = recvfrom(sock, buffer, sizeof(buffer) - 1, 0, (struct sockaddr*)&fromAddr, &fromAddrLen);
        if (respLength > 0) {
            buffer[respLength] = '\0';  //add a null terminate to the received string
            cout << "Received response from Linux PC: " << buffer << endl;
            confirmed = true;
        } else {
            cout << "No response received, retrying..." << endl;
        }
    }

    close(sock); //close the socket once everything is finished
}



File_Monitor* file_Monitor = nullptr;
std::thread monitor_files_thread;

void runMonitoringThread() {
    file_Monitor = new File_Monitor(Directory_Parameters::RPi_Save_Directory);
    file_Monitor->Monitor_Directory(); 
}


int Raw_Image_Reconstruction(const char* filename) {
    cout << "In recon func" << endl;
    if (!Py_IsInitialized()) {
        Py_Initialize();
        PyRun_SimpleString("import sys");
        PyRun_SimpleString("sys.path.append('.')");
    }

    PyObject* pModule = PyImport_ImportModule("image_processing");
    if (!pModule) {
        PyErr_Print();
        cerr << "Failed to import\n";
        return -1;
    }

    PyObject* pFunc = PyObject_GetAttrString(pModule, "process_image");
    if (pFunc && PyCallable_Check(pFunc)) {
        PyObject* pDict = PyDict_New();
        for (const auto& pair : Post_Processing_Parameters_Map) {
            PyObject* pKey = PyUnicode_FromString(pair.first.c_str());
            PyObject* pValue = PyUnicode_FromString(pair.second.c_str());
            PyDict_SetItem(pDict, pKey, pValue);
            Py_DECREF(pKey);
            Py_DECREF(pValue);
        }

        PyObject* pArgs = PyTuple_Pack(2, PyUnicode_FromString(filename), pDict);
        PyObject* pResult = PyObject_CallObject(pFunc, pArgs);
        if (!pResult) PyErr_Print();
        Py_XDECREF(pArgs);
        Py_XDECREF(pDict);
        Py_XDECREF(pResult);
    } else {
        PyErr_Print();
        cerr << "Failed to call process_image function\n";
    }

    Py_XDECREF(pFunc);
    Py_XDECREF(pModule);

    return 0;
} 

//called after the client has connected to the broker
void on_connect(struct mosquitto *mosq,	//pointer to our clients object
		void *obj, // pointer to clients ID
		int rc) // return code of connect function (error codes)
		{
			
	printf("ID: %d\n", * (int *) obj);
	
//----------------------Error Checking----------------------
	if(rc) {
		printf("Error with result code: %d\n", rc);
		exit(-1);
	}
//----------------------------------------------------------


//-----------subscribe if connection was successful------------

	mosquitto_subscribe(mosq,  //Clients Object
			    NULL,  //Message ID	
			    "Image_Format", //Topic to subscribe to				
			     0); //quality of service level (QoS)
			     
	mosquitto_subscribe(mosq,  //Clients Object
			    NULL,  //Message ID	
			    "RPI_Save_Directory", //Topic to subscribe to
			     0); //quality of service level (QoS)
			
	mosquitto_subscribe(mosq,  //Clients Object
			    NULL,  //Message ID	
			    "Image_Processing_Options", //Topic to subscribe to
			     0); //quality of service level (QoS)

	mosquitto_subscribe(mosq,  //Clients Object
			    NULL,  //Message ID	
			    "Take_Image", //Topic to subscribe to
			     0); //quality of service level (QoS)
			     
	mosquitto_subscribe(mosq,  //Clients Object
			    NULL,  //Message ID	
			    "PC_Save_Directory", //Topic to subscribe to
			     0); //quality of service level (QoS)
			     
	mosquitto_subscribe(mosq,  //Clients Object
			    NULL,  //Message ID	
			    "Advanced_Image_Processing_Options", //Topic to subscribe to
			     0); //quality of service level (QoS)
			    
	mosquitto_subscribe(mosq,  //Clients Object
			    NULL,  //Message ID	
			    "Cyan_LED_Brightness_Value", //Topic to subscribe to
			     0); //quality of service level (QoS)
			 
	mosquitto_subscribe(mosq,  //Clients Object
			    NULL,  //Message ID	
			    "Red_LED_Brightness_Value", //Topic to subscribe to
			     0); //quality of service level (QoS)
			  
	mosquitto_subscribe(mosq,  //Clients Object
			    NULL,  //Message ID	
			    "Green_LED_Brightness_Value", //Topic to subscribe to
			     0); //quality of service level (QoS)
			     
	mosquitto_subscribe(mosq,  //Clients Object
			    NULL,  //Message ID	
			    "Blue_LED_Brightness_Value", //Topic to subscribe to
			     0); //quality of service level (QoS)
			     
	mosquitto_subscribe(mosq,  //Clients Object
			    NULL,  //Message ID	
			    "PWM_Frequency", //Topic to subscribe to
			     0); //quality of service level (QoS)
			     
	mosquitto_subscribe(mosq,  //Clients Object
			    NULL,  //Message ID	
			    "WhoAmI", //Topic to subscribe to
			     0); //quality of service level (QoS)
			    
	mosquitto_subscribe(mosq,  //Clients Object
			    NULL,  //Message ID	
			    "Linux_PC_IP", //Topic to subscribe to
			     0); //quality of service level (QoS)
			     
	mosquitto_subscribe(mosq,  //Clients Object
			    NULL,  //Message ID	
			    "Program_Closed", //Topic to subscribe to
			     0); //quality of service level (QoS)
			     
	mosquitto_subscribe(mosq,  //Clients Object
			    NULL,  //Message ID	
			    "PWM_Pins", //Topic to subscribe to
			     0); //quality of service level (QoS)

}
//-------------------------------------------------------------


struct MQTTHandler {
    int Image_Format_Value;
    int Image_Processing_Options_Value;
    string RPI_Save_Directory_Value;
};

MQTTHandler test;



//--------------------MQTT on recieving message from subscribe--------------------
inline void on_message(struct mosquitto *mosq, //Pointer to our Clients Object
	 	void *obj, //Pointer to message ID
	 	const struct mosquitto_message *msg) // Struct containging message data
{	


		printf("New message with topic %s: %s\n", msg->topic, (char *) msg->payload); //Print the recieved message
	
	if(!strcmp(msg->topic,"Image_Format"))//this compares the string msg->topic to HV_Topic and returns 0 if true thus the !strcmp
	{

		cout << "message on topic : Image_Format" << endl;
		test.Image_Format_Value = atoi((char *) msg->payload); // convert char* payload to integer value
		
		cout << test.Image_Format_Value << endl;
		
		
	}
	
	
	if(!strcmp(msg->topic,"RPI_Save_Directory"))//this compares the string msg->topic to HV_Topic and returns 0 if true thus the !strcmp
	{

		cout << "message on topic : RPI_Save_Directory" << endl;
		
	    Directory_Parameters::RPi_Save_Directory = (char *) msg->payload;
	
		
    		std::cout << "RPi directory: " << Directory_Parameters::RPi_Save_Directory << std::endl;
		
    		std::filesystem::path dirPath(Directory_Parameters::RPi_Save_Directory);
		
    		//check if the path is an absolute path and either doesnt exist or already exists
    		if (dirPath.is_absolute()) {
    		    if (!std::filesystem::exists(dirPath)) {
    		        //path is absolute but does not exist so create it
    		        if (std::filesystem::create_directories(dirPath)) {
    		            std::cout << "The directory was successfully created." << std::endl;
		
    		            Directory_Parameters::Confirmed_Correct_RPi_Save_Directory = Directory_Parameters::RPi_Save_Directory;
		
    		            //setup a thread for monitoring files
    		            std::thread monitor_files_thread(runMonitoringThread);
    		            monitor_files_thread.detach(); //detach the thread to allow it to run independently of main thread
    		        }
    		    } else {
    		        // Here the path is absolute and already exists on the system.
    		        std::cout << "The path already exists on the system." << std::endl;
		
    		        Directory_Parameters::Confirmed_Correct_RPi_Save_Directory = Directory_Parameters::RPi_Save_Directory;
		
    		        //setup a thread for monitoring files.
    		        std::thread monitor_files_thread(runMonitoringThread);
    		        monitor_files_thread.detach(); //detach the thread to allow it to run independently of main thread
    		    }
		
    		    //subdirectory names
    		    std::string subdirs[] = {"tiff", "dng", "png"};
		
    		    //check and create subdirectories if they don't exist, inside the absolute path the user entered
    		    for (const std::string& subdir : subdirs) {
    		        std::filesystem::path subdirPath = dirPath / subdir;
    		        if (!std::filesystem::exists(subdirPath)) {
    		            if (std::filesystem::create_directory(subdirPath)) {
    		                std::cout << "Subdirectory for " << subdir << " was successfully created." << std::endl;
    		            }
    		        } else {
    		            std::cout << "Subdirectory for " << subdir << " already exists." << std::endl;
    		        }
    		    }
    		} else {
    		    // The path is not absolute, thus is invalid.
    		    std::cout << "This is an invalid path. Please provide a full, absolute path." << std::endl;
    		}

}

	
	
	if(!strcmp(msg->topic,"Image_Processing_Options"))//this compares the string msg->topic to HV_Topic and returns 0 if true thus the !strcmp
	{

        cout << "message on topic: Image_Processing_Options" << endl;

        string Indexed_User_Selected_Processing_Options = (char *)msg->payload;
        std::vector<int> User_Selected_Indexed_Processing_Options;
        std::stringstream ss(Indexed_User_Selected_Processing_Options); 
        string Temporary_Holder;

        while (std::getline(ss, Temporary_Holder, ',')) {
            User_Selected_Indexed_Processing_Options.push_back(std::stoi(Temporary_Holder));
        }

        Post_Processing_Parameters_Map.clear();

        for (int selection : User_Selected_Indexed_Processing_Options) {
            auto it = selectionToParameters.find(selection);
            if (it != selectionToParameters.end()) {
                Post_Processing_Parameters_Map[it->second.first] = it->second.second;
            } else {
                cout << "Selection not recognized: " << selection << endl;
            }
        }

        for (const auto& pair : Post_Processing_Parameters_Map) {
            cout << "Key: " << pair.first << ", Value: " << pair.second << endl;
        }


		
}




	if(!strcmp(msg->topic,"Take_Image"))//this compares the string msg->topic to Take_Image and returns 0 if true thus the !strcmp
	{

		//cout << "message on topic : Take_Image" << endl;
		//int Recived_Take_Image_Value = atoi((char *) msg->payload); // convert char* payload to integer value
		//cout << "Recived Value: " << Recived_Take_Image_Value << endl;
		MQTT_Publisher publisher("publisher-test", IPAddress::getInstance().getAddress(), 1883);
		publisher.publish("Take_Image", "Image Taken Now");
		
		//cout << test.Image_Format_Value << endl;

		//decision made to not put system in to prevent raw reconstruction from being called while
		//processing an image, as a delay will be added to GUI to only allow button to be pressed
		//every X seconds
	
		
		string Current_Time = DateTime::getInstance().getDateTime();

		string command = "libcamera-still -t 5 -r -o " + Directory_Parameters::Confirmed_Correct_RPi_Save_Directory + "/" + "Image_" + Current_Time + ".dng"; //-t 5 means wait 5ms -r means take raw image
		
		
		
		//cout << command << endl;
		
		system(command.c_str()); 
		
		
		string Path_for_Image_Processing = Directory_Parameters::Confirmed_Correct_RPi_Save_Directory + "/" + File_Monitor_Parameters::Created_Image_File_Name;
		
		cout << "im process path" << Path_for_Image_Processing << endl;
		
		//cout << "File Name "<< File_Monitor_Parameters::Created_Image_File_Name <<endl;
		
		Raw_Image_Reconstruction(Path_for_Image_Processing.c_str());
		
		
		
		string File_Type_Sub_Directories[] = {"/dng", "/tiff", "/png"};
		string File_Extension_Types[] = {".dng", ".tiff", ".png"};
		string SCP_Full_Path_To_All_Sub_Directories[3];
		string File_Transfer_Command = "";
		string File_Name_No_Extension = "";
		File_Name_No_Extension = removeExtension(File_Monitor_Parameters::Created_Image_File_Name);
		
		
		cout << "----------------------here---------------------"<< endl;
		
		
//-------------------populates an array with correct directory paths and sends the files over scp-------------------
		for(uint8_t i = 0; i<= 2; ++i){//dont know why this didnt work inside just one for loop cause with just 1 the scp commands didnt execute
			SCP_Full_Path_To_All_Sub_Directories[i] = Directory_Parameters::Confirmed_Correct_RPi_Save_Directory + File_Type_Sub_Directories[i];		
		}
		
		for(uint8_t i = 0; i<= 2; ++i){
			//replace /home/ with the location of the SSH key, also not required to have StrictHostKeyChecking = no
			File_Transfer_Command = "scp -o StrictHostKeyChecking=no -i /home/ " + SCP_Full_Path_To_All_Sub_Directories[i] + "/" + File_Name_No_Extension + File_Extension_Types[i] + " " + Linux_PC_SCP_Parameters::Linux_PC_WhoAmI +  "@"  + Linux_PC_SCP_Parameters::Linux_PC_IP + ":" + Directory_Parameters::PC_Save_Directory;
			
			cout << "File trans cmd: " << File_Transfer_Command << endl;
			system(File_Transfer_Command.c_str());
		}
//-----------------------------------------------------------------------------------------------------------------
			
}
	
		
	if(!strcmp(msg->topic,"PC_Save_Directory"))//this compares the string msg->topic to PC_Save_Directory and returns 0 if true thus the !strcmp
	{
		cout << "message on topic : PC_Save_Directory" << endl;
	    Directory_Parameters::PC_Save_Directory = (char *) msg->payload;
	}
	

	if(!strcmp(msg->topic,"Advanced_Image_Processing_Options")) { //this compares the string msg->topic to Advanced_Image_Processing_Options and returns 0 if true thus the !strcmp
		cout << "Message on topic: Advanced_Image_Processing_Options" << endl;
  		string Received_Advanced_Processing_Options = (char *)msg->payload; //stores all the advanced processing options with semi colon delimiter

		//these local variable copies were needed as without them when just assigning values to the namespace variables
    	//it would have to run twice to see the user input because by default the namespace values are null, so these are
    	//used to get the value then assign to the namespace so it always contains up to date data, not ideal but is a work around.
 	 	string Custom_Brightness_Value;
    	string Custom_White_Balance_Value;
    	string Custom_Gamma_Value;

    	std::stringstream ss(Received_Advanced_Processing_Options);
    	string segment;
    	int segmentCount = 0;

    	//try to read each segment from the stringstream
    	while(std::getline(ss, segment, ';')) {
        	if(segmentCount == 0) Custom_Brightness_Value = segment;
        	else if(segmentCount == 1) Custom_White_Balance_Value = segment;
        	else if(segmentCount == 2) Custom_Gamma_Value = segment;
        	++segmentCount;
    	}

//---------------only update the map and variables if the values have been received---------------
    	if(!Custom_Brightness_Value.empty()) {
        	Post_Processing_Parameters_Map["bright"] = Custom_Brightness_Value;
        	Updated_Advanced_Image_Processing_Options_Parameters::Custom_Brightness_Value_Updated = Custom_Brightness_Value;
        	cout << "Brightness: " << Custom_Brightness_Value << endl;
    	}

    	if(!Custom_White_Balance_Value.empty()) {
        	Post_Processing_Parameters_Map["user_wb"] = Custom_White_Balance_Value;
        	Updated_Advanced_Image_Processing_Options_Parameters::Custom_White_Balance_Values_Updated = Custom_White_Balance_Value;
        	cout << "user_wb: " << Custom_White_Balance_Value << endl;
    	}

    	if(!Custom_Gamma_Value.empty()) {
        	Post_Processing_Parameters_Map["gamma"] = Custom_Gamma_Value;
        	Updated_Advanced_Image_Processing_Options_Parameters::Custom_Gamma_Values_Updated = Custom_Gamma_Value;
        	cout << "gamma: " << Custom_Gamma_Value << endl;
    	}
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
int main() {
	 std::signal(SIGINT, Handle_Signal);

	sendIPAddressAndAwaitConfirmation();
    
//   monitor_files_thread = std::thread(runMonitoringThread); //make a thread
//    monitor_files_thread.detach();//Detach the thread to allow it to run independently
    

    MQTT_Subscribe_Handling mqttHandling; // this could also potentially be run on its own thread.
    mqttHandling.subscribe();
    
    
    
   delete file_Monitor; 
    
    return 0;
}

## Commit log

2024-05-28 Create folder for CAD designs
2024-05-28 LED based illumination PCB for multi-modal imaging
    3 LED rings 18 LEDs per ring, one ring per imaging modality, allows for brightfield, darkfield and phase contrast. Also provides different mounting options such as Thor Labs 30 and 60mm cage plates, 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
    Note when tested wasnt fully functional, thought to be due to fact it was hand soldered with 0402 components with solder paste with no stencil. Its believed if professionally manufactured and populat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
    [Blue LEDs.kicad_sch, Green LED.kicad_sch, Hole Edge Cuts 2.5mm v6.dxf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]
2024-05-29 Code developed that runs on the Raspberry Pi 4
2024-05-29 All relevant file/code that runs on the raspberry pi 4
    Contains all code for the microscope control on the pi 4 side, including additional files such as memory tests and files for image processing including the cython code, setup.py file and the .SO file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
